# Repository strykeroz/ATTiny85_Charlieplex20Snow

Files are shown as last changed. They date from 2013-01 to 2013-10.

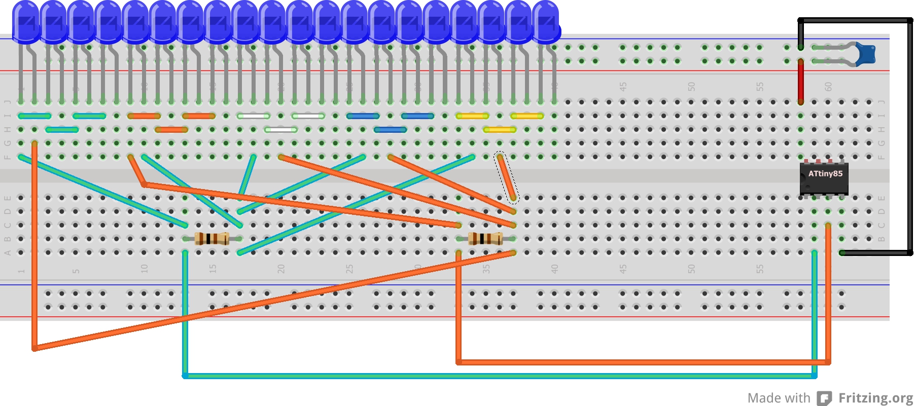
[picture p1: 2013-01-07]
Partial charlie20snow_bb.jpg

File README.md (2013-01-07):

ATtiny85 "Snow" with 20 Charlieplexed LEDs
==========================================

ATtiny85 Xmas decorative effect, using Arduino core 

This project creates a falling snowflake effect (or rain?) as discussed in this Arduino forum thread: http://arduino.cc/forum/index.php/topic,135596.15.html

The animation has a bright LED at the head, and a tail of 4 others which fall at a slightly randomised speed, with a random delay between falls.  The animation slows during the fall, and the "snowflake" rests at the bottom while the tail collapses into it, before finally fading away.

Operation
---------
Animation operates while powered on.

ATtiny85 pin assignments 
------------------------
(legs numbered 1..8 counterclockwise from leg marked with dot)
 Leg  Function
 1    Reset, no connection
 2    D3 GREEN channel
 3    D4 ORANGE channel
 4    GND
 5    D0 WHITE channel
 6    D1 BLUE channel
 7    D2 YELLOW channel
 8    +5V

Code
----
Written using the Arduino IDE and Arduino-Tiny cores , the target to select is the ATtiny85 @ 8MHz (internal oscillator, BOD disabled).  Look up how to program the ATtiny using Arduino, and programming it using Arduino as an IDE.  

Tested installation
-------------------
For simplicity of wiring on breadboard, and for matching to function in the code, this was wired using a colour code.  A breadboard circuit diagram created in Fritzing is included to explain how two of those channels are wired.

I started the breadboard with a row of 20 LEDs, each with the flat side to the right.  For a more permanent installation, rotating the LEDs so the flat side is top or bottom would allow for ease of wiring.  Each group of 4 LEDs shares a direct connection to one pin directly without a resistor, with the 4 anodes (+, or the long LED leg) linked.  Then the other legs are connected via a current limiting resistor to the other colours in the sequence green, orange, white, blue, yellow (always in this order, but omitting of course the colour that the anodes are).

So the green group has green to the anodes, then the cathodes in left to right sequence are orange, white, blue & yellow.  The orange group has orange to the anodes, with green, white, blue & yellow to the cathodes left to right.  White group's cathodes are sequenced green, orange, blue & yellow; the blue group's cathodes go green, orange, white & yellow; and the yellow group's cathodes go green, orange, white & blue.

BoM as tested:
	1x ATtiny85-20PU
	1x 8 pin DIP IC Socket (optional, you might be confident soldering direct to the ATtiny to reduce weight)
	20x 5mm blue LED
	5x 100 Ohm resistors (current limiting, for LEDs)
	1x 0.1uF ceramic capacitor (decoupling)

Be sure to choose current limiting resistors to suit the particular LED you select.
  
Enjoy : )

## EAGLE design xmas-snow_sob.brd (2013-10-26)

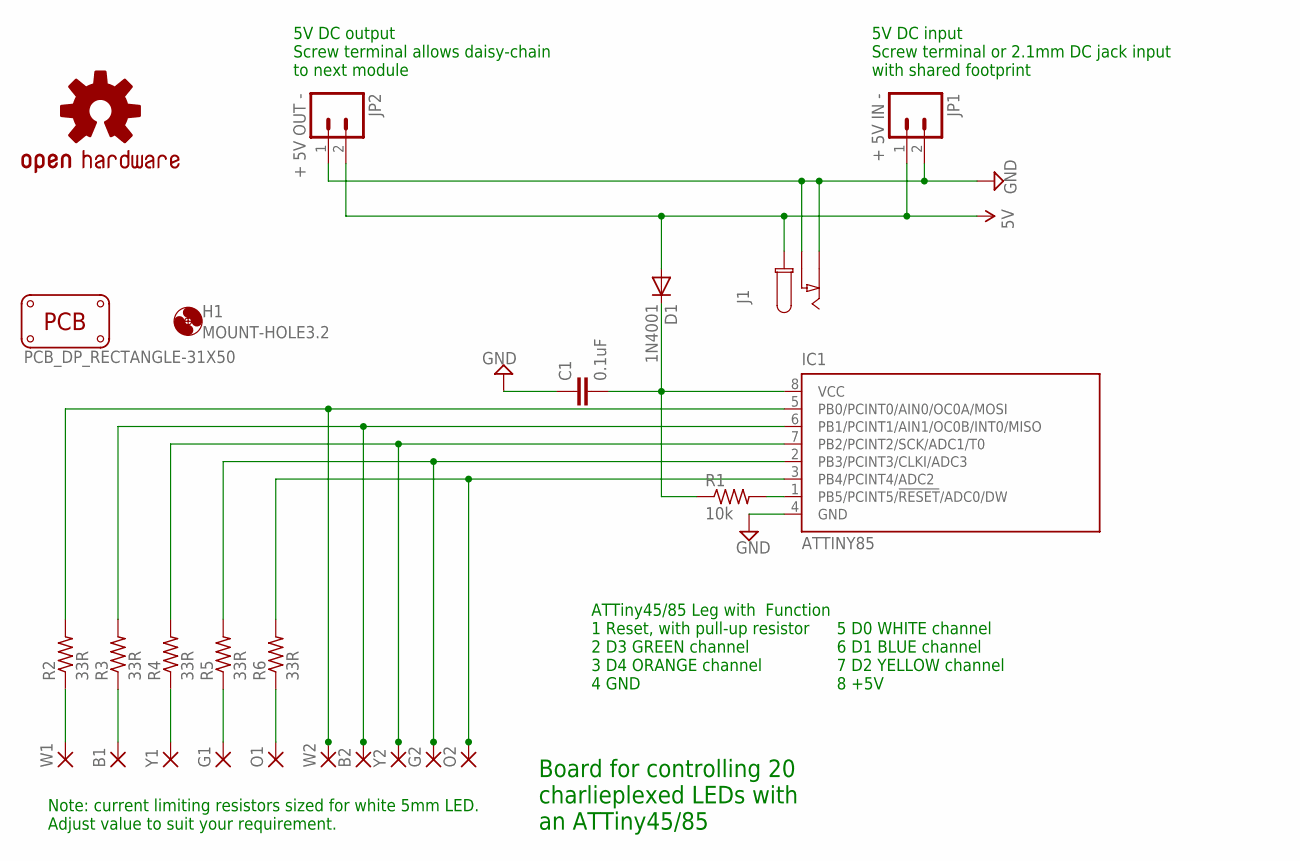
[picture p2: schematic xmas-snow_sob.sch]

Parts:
B1, B2: WIREPAD1,6/0,8; 1,6/0,8
C1: 0.1uF; CAP-PTH-SMALL2
D1: 1N4001; DO41-10
G1, G2: WIREPAD1,6/0,8; 1,6/0,8
H1: MOUNT-HOLE3.2; 3,2
IC1: ATTINY85; DIL08
J1: CON_DC_M-DC_PTH; DC_BARREL_JACK_PTH_2MM
JP1: + 5V IN -; SCREWTERMINAL-5MM-2
JP2: + 5V OUT -; SCREWTERMINAL-5MM-2
LOGO1: OSHW-LOGOL; OSHW-LOGO-L
O1, O2: WIREPAD1,6/0,8; 1,6/0,8
PCB1: PCB_DP_RECTANGLE-31X50; DP5031_V1
R1: 10k; 0207/2V
R2, R3, R4, R5, R6: 33R; 0207/2V
W1, W2: WIREPAD1,6/0,8; 1,6/0,8
Y1, Y2: WIREPAD1,6/0,8; 1,6/0,8

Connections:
5V: C1.2, D1.A, D1.C, IC1.8 (VCC), J1.P1, JP1.1, JP2.2, R1.1
GND: C1.1, IC1.4 (GND), J1.P2 (P3), J1.P3 (P2), JP1.2, JP2.1
unnamed: IC1.1 (PB5/PCINT5/!RESET!/ADC0/DW), R1.2
unnamed: IC1.5 (PB0/PCINT0/AIN0/OC0A/MOSI), R2.2, W2.1
unnamed: B2.1, IC1.6 (PB1/PCINT1/AIN1/OC0B/INT0/MISO), R3.2
unnamed: IC1.7 (PB2/PCINT2/SCK/ADC1/T0), R4.2, Y2.1
unnamed: G2.1, IC1.2 (PB3/PCINT3/CLKI/ADC3), R5.2
unnamed: IC1.3 (PB4/PCINT4/ADC2), O2.1, R6.2
unnamed: R2.1, W1.1
unnamed: B1.1, R3.1
unnamed: R4.1, Y1.1
unnamed: G1.1, R5.1
unnamed: O1.1, R6.1

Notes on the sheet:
ATTiny45/85 Leg with Function 1 Reset, with pull-up resistor 2 D3 GREEN channel 3 D4 ORANGE channel 4 GND
Board for controlling 20 charlieplexed LEDs with an ATTiny45/85
5V DC input Screw terminal or 2.1mm DC jack input with shared footprint
5V DC output Screw terminal allows daisy-chain to next module
5 D0 WHITE channel 6 D1 BLUE channel 7 D2 YELLOW channel 8 +5V
Note: current limiting resistors sized for white 5mm LED. Adjust value to suit your requirement.

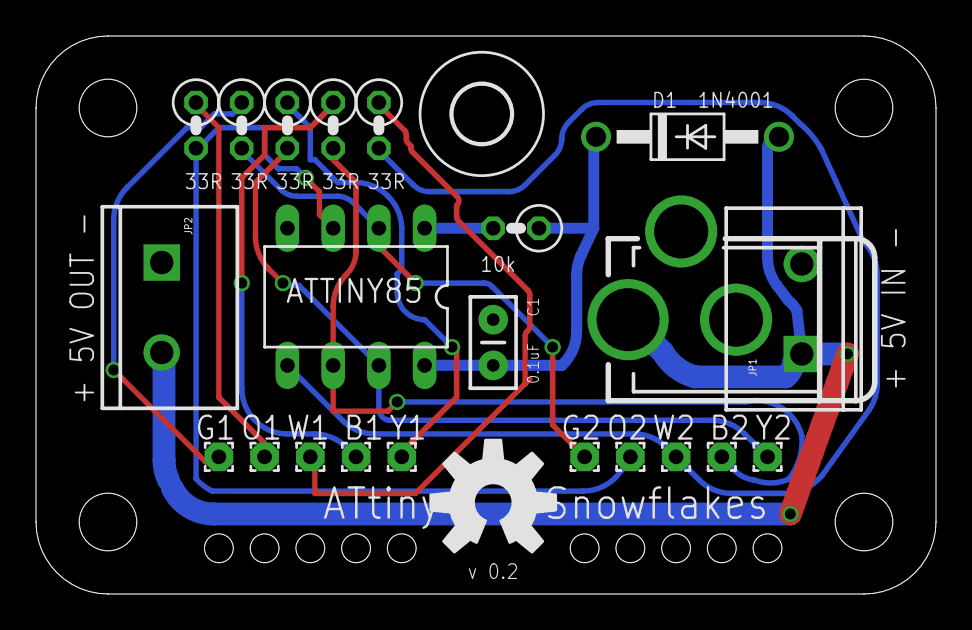
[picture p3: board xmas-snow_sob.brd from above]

Board: 2 copper layers, 50.0 x 31.0 mm, 25 parts (0 on the bottom side), 13 nets.

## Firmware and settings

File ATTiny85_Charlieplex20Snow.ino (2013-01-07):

#include <Entropy.h>
// downloaded from http://code.google.com/p/avr-hardware-random-number-generation/

/*
   ____ _                _ _            _           ____   ___                          
  / ___| |__   __ _ _ __| (_) ___ _ __ | | _____  _|___ \ / _ \ ___ _ __   _____      __
 | |   | '_ \ / _` | '__| | |/ _ \ '_ \| |/ _ \ \/ / __) | | | / __| '_ \ / _ \ \ /\ / /
 | |___| | | | (_| | |  | | |  __/ |_) | |  __/>  < / __/| |_| \__ \ | | | (_) \ V  V / 
  \____|_| |_|\__,_|_|  |_|_|\___| .__/|_|\___/_/\_\_____|\___/|___/_| |_|\___/ \_/\_/  
                                 |_|                                                    
 
 Charlieplexing 20 LEDs using 5 ATTiny85 pins with fading by
 varying the duty cycle of each LED in the 'tail'.
 
 ATTiny85 connections
 Leg  Function
 1    Reset, no connection
 2    D3 GREEN
 3    D4 ORANGE
 4    GND
 5    D0 WHITE
 6    D1 BLUE
 7    D2 YELLOW
 8    +5V
 
 Tested on ATTiny85 running at 8MHz.
 */

// each block of 4 LEDs in the array is groupled by a common anode (+, long leg)
// for simplicity of wiring on breadboard, using a colour code
#define GREEN 0
#define ORANGE 1
#define WHITE 2
#define BLUE 3
#define YELLOW 4

// pin definitions {GREEN, ORANGE, WHITE, BLUE, YELLOW}
const int charliePin[5] = {
  3, 4, 0, 1, 2};

// Charlieplexed LED definitions (current flowing from-to pairs)
const int LED[20][2] = {
  {
    ORANGE, GREEN      }
  ,                            // 0 (GREEN GROUP)
  {
    WHITE, GREEN      }
  ,                             // 1
  {
    BLUE, GREEN      }
  ,                              // 2
  {
    YELLOW, GREEN      }
  ,                            // 3
  {
    GREEN, ORANGE      }
  ,                            // 4 (ORANGE GROUP)
  {
    WHITE, ORANGE      }
  ,                            // 5
  {
    BLUE, ORANGE      }
  ,                             // 6
  {
    YELLOW, ORANGE      }
  ,                           // 7
  {
    GREEN, WHITE      }
  ,                             // 8 (WHITE GROUP)
  {
    ORANGE, WHITE      }
  ,                            // 9
  {
    BLUE, WHITE      }
  ,                              // 10
  {
    YELLOW, WHITE      }
  ,                            // 11
  {
    GREEN, BLUE      }
  ,                              // 12 (BLUE GROUP)
  {
    ORANGE, BLUE      }
  ,                             // 13
  {
    WHITE, BLUE      }
  ,                              // 14
  {
    YELLOW, BLUE      }
  ,                             // 15
  {
    GREEN, YELLOW      }
  ,                            // 16 (YELLOW GROUP)
  {
    ORANGE, YELLOW      }
  ,                           // 17
  {
    WHITE, YELLOW      }
  ,                            // 18
  {
    BLUE, YELLOW      }                              // 19
};

// other
int current = 0;                              // LED in array with current focus
int previous = 0;                             // previous LED that was lit

void setup() {
  Entropy.Initialize();
  randomSeed(Entropy.random());
}

void loop() {
  unsigned long loopCount = 0;                          // used to determine duty cycle of each LED
  unsigned long timeNow = millis();                     //
  unsigned long displayTime = 10 + random(90);          // milliseconds to spend at each focus LED in descent
  while(millis()- timeNow < (displayTime+current*2)) {  // animation slows toward end
    loopCount++;
    // the "snowflake" gets full duty cycle.  When it gets to the end, hold it at the end until the tail collapses
    if (current > 19) charlieON(19); 
    else charlieON(current);
    // each member of tail has reduced duty cycle, and never get to the final position
    if(!(loopCount % 3)) if(current-1 >=0 && current-1 < 19) charlieON(current-1);
    if(!(loopCount % 6)) if(current-2 >=0 && current-2 < 19) charlieON(current-2);
    if(!(loopCount % 9)) if(current-3 >=0 && current-3 < 19) charlieON(current-3);
    if(!(loopCount % 12)) if(current-4 >=0 && current-4 < 19) charlieON(current-4);
  }

  current++;
  if(current==23) {                          // start over
    // now fade out the snowflake in that final position #19
    for(int dutyCycle = 3; dutyCycle <= 15; dutyCycle += 3) {
      loopCount = 0;
      timeNow = millis();
      while(millis() - timeNow < (displayTime+current*2)) { // fade out as slow as animation has achieved by now
        loopCount++;
        if(!(loopCount % dutyCycle)) charlieON(19); 
        else charlieOFF(19);
      } 
    }
    current = 0;
    charlieOFF(19);                          // turn off the remaining (possibly) lit LED
    delay(100 + random(3000));               // and then rinse, repeat...after a short pause
  }
}

// --------------------------------------------------------------------------------
// turns on LED #thisLED.  Turns off all LEDs if the value passed is out of range
//
void charlieON(int thisLED) {
  // turn off previous (reduces overhead, only switch 2 pins rather than 5)
  digitalWrite(charliePin[LED[previous][1]], LOW);   // ensure internal pull-ups aren't engaged on INPUT mode
  pinMode(charliePin[LED[previous][0]], INPUT);
  pinMode(charliePin[LED[previous][1]], INPUT);

  // turn on the one that's in focus
  if(thisLED >= 0 && thisLED <= 19) {
    pinMode(charliePin[LED[thisLED][0]], OUTPUT);
    pinMode(charliePin[LED[thisLED][1]], OUTPUT);
    digitalWrite(charliePin[LED[thisLED][0]], LOW);
    digitalWrite(charliePin[LED[thisLED][1]], HIGH);
  }
  previous = thisLED;
}

// --------------------------------------------------------------------------------
// turns off LED #thisLED.  
//
void charlieOFF(int thisLED) {
  digitalWrite(charliePin[LED[thisLED][1]], LOW);   // ensure internal pull-ups aren't engaged on INPUT mode
  pinMode(charliePin[LED[thisLED][0]], INPUT);
  pinMode(charliePin[LED[thisLED][1]], INPUT);
}

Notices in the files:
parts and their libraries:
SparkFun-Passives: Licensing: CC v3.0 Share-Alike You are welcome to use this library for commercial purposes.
